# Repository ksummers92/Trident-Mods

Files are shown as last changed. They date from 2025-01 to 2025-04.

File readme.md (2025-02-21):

- Reaper Toolhead Mods directory contains mods/remixes used that relate to the [Reaper Toolhead](https://github.com/APDMachine/Reaper) ecosystem.
- Gantry Blobifier is a modified version of [Blobifier_X](https://github.com/xuanyuanss/Blobifier_X) which is a variant of [Blobifier](https://github.com/Dendrowen/Blobifier).

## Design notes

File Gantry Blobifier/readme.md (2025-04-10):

# Gantry-Attached Blobifier
## A variant of Blobifier for fixed XY gantry printers

First of all, this variant is based heavily on the "[Blobifier_X](https://github.com/xuanyuanss/Blobifier_X)". Credit to the originator for a great idea!

The Blobifier hardware is wholly incompatible with fixed gantry printers such as the Voron Trident.

There are variations of the "software" that the Blobifier uses to operate that allow one to purge blobs onto the bed and then kick them off. However, this method poses similar and additional issues that are present in the original Blobifier.

1. An area of the build plate is lost/reserved for purging in both the original Blobifier (primarily for toolhead clearance) and the Trident/SW variant of blobbing on the build plate.
1. The Trident/SW variant has a further limitation due to the need to raise the bed/lower the X-axis gantry to bed which either limits the height of parts to the height of the toolhead below the gantry or makes it not possible to use the Blobifier for parts taller than that dimension.

While attempting to implement the Blobifier_X, I found that the unipolar stepper motor (despite "conversion" to a bipolar stepper) was inadequate for the task and tempermental. Therefore, I decided to make some modifications to the original design to enable the use of a NEMA 17 stepper that I had laying around.

> Note: While I designed this for my Trident, the original designer designed theirs for the V2. Therefore, this could in theory be used for a V2 also. However, there are certain design considerations that would need taken into account for this version to work effectively with a V2. Primarily, overall height of the setup would need to be closely considered to allow the gantry to still reach the build plate. The weight is also a factor to consider. However, the advantage of not losing build area may be worth it.

# Images
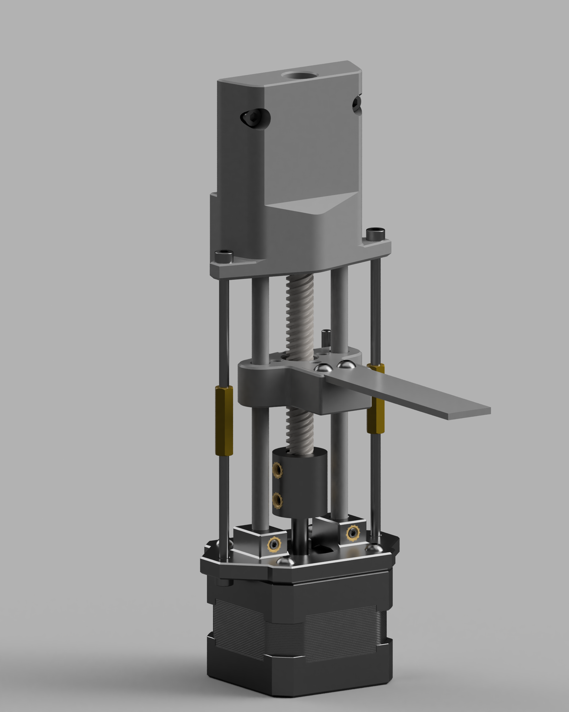
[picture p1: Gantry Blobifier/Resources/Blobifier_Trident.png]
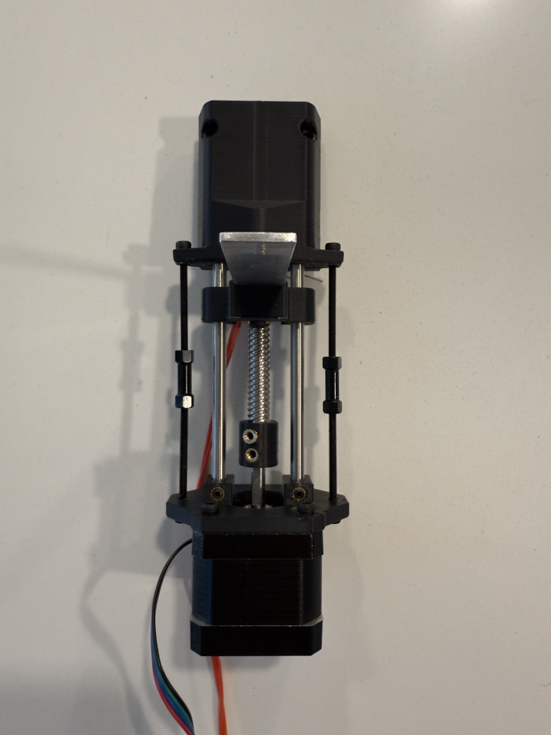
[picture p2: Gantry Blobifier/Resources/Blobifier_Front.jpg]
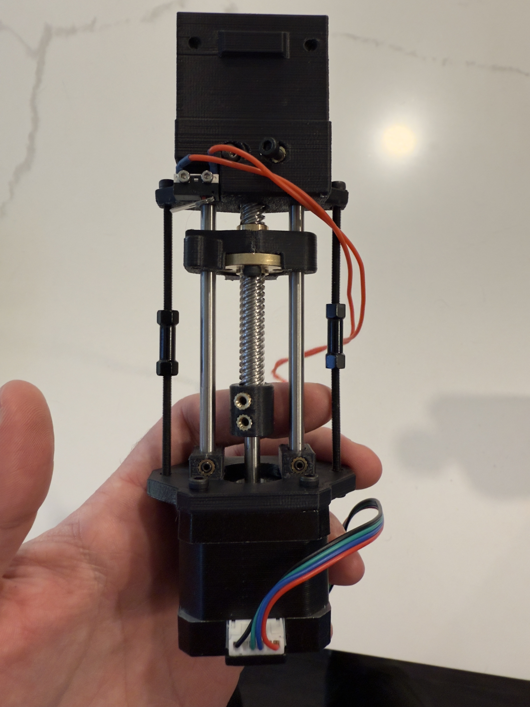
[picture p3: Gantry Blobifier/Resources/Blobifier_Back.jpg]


# In Action
Watch the Video (https://youtu.be/DP9UL1YaNPk)

> WARNING: Improper configuration of this setup and macro could result in damage to your printer. I am not responsible for any damages caused as a result of your actions. That being said, I am willing to assist if you are having any issues.

# Bill of Materials:
- 1x NEMA 17 stepper motor, I do not think that the size is important since the assembly is relatively light, so opt for the smallest variant you have on hand.
- 1x TMC2209 or any bipolar stepper motoro driver
- 2x ∅5x100mm steel dowel
	- I used 100mm length, but this can be tuned to your setup. 100mm works well with the Reaper Toolhead using a Rapido UHF hotend where the nozzle tip sits ~49mm below the bottom side of the gantry extrusion.
- 1x 100mm T8 lead screw with nut
	- Again, the length can be changed for your setup. There is some forgiveness in the length since the top side is not fixed in place
	- Generally, the length should be the same as the length of the dowels you chose.
- 1x D2F-L1 micro switch, knockoff Omrons work too
- Some amount of M3x4x5 heatset inserts (~12? ¯\\_(ツ)_/¯)
- 4-8x M3x3 set screws
	- Minimum 4 if you decide to print the coupler, optional additional 4 (8 total) if you want to use set screws for attach the stepper mount to the rods.
- 2x M3x12 SHCS for attaching to 2020 extrusions
- 2x t-nuts for 2020 extrusion attachment
- 4x M3x8 BHCS or SHCS for attaching stepper to stepper mount
- 2x M3x12 BHCS for securing rods to main body
	- Could use longer set screws too
- 1x M3x? BHCS or SHCS for endstop positioning
	- Length is variable because it depends on your setup
- 2x M3x6 BHCS or SHCS for mounting tray to slider
- 4x M3x40mm BHCS or SHCS for support rods
	- Length of these will depend on the length of the dowels that you choose and the length of spacer you have.
	- Generally, the length of the screws should be less than half the length of the rods (recommend (length_of_rod/2)-10) and choose spacer appropriately.
- 2x M3x25mm spacer for mating the support bolts together
	- <s>Strictly speaking, these and the 40mm bolts above may not be necessary, but I added them as a backup in the event that the screws holding the rods in place backed out over time from vibrations. You can add loctite to these, I would not recommend adding loctite to the screws holding the rods. </s>
	- After extended use, when I took the blobifier apart, I found that my set screws had loosened. Therefore, I believe that these support rods are good insurance.
- 1x 15x2x?mm aluminum bar for tray
	- You want this long enough to extend about 4-5mm past nozzle when nozzle parked over tray.
	- I suggest buying longer than needed and cutting to length once you have everything mocked up.
	- Drill holes into bar as shown below
- Masking tape, aids in adherence of blob to tray. Other methods could also work, this just worked for me.

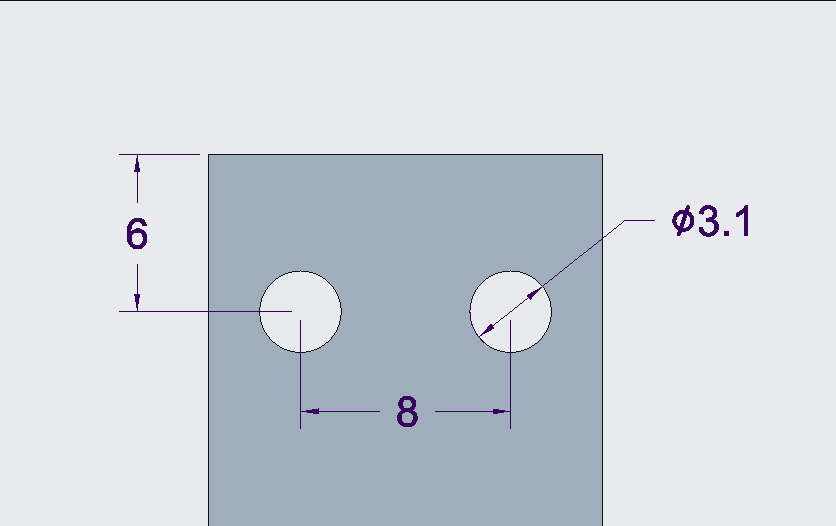
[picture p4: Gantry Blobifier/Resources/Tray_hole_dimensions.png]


# Key Assembly Instructions
- If using printed coupler, I suggest installing the stepper mount shaft and T8 rod into coupler and then pressing the heatset insert all the way until it stops against the shaft/rod.
- Assemble the main body and the stepper motor mount with the rods, then install the T8 shaft with the coupler onto the stepper motor before attaching stepper to the mount.
- If using the printed standoff, there are two options for attaching with bolts: insert a M3 nut into the recess or use a M3x5x4 heatset insert. 
	- There is no need to torque the support bolts significantly as they are just keeping the assembly together. Overtorquing may lead to printed part failure, so use the Voron adage "Tighten until the plastic bends and cracks. Back up 2 turns, discard parts, reprint and try again".

# Setup Instructions
## Basic Configuration
- Copy blobifier_trident.cfg and blobifier_trident_hw.cfg to config folder.
	- Add [include blobifier_trident.cfg] and [include blobifier_trident_hw.cfg] to printer.cfg
- Update the pin definitions, rotation distance, etc. in blobifier_trident_hw.cfg to match your setup.
- Check the stepper motor direction by manually putting the slider in the middle of the travel, then run `MANUAL_STEPPER STEPPER=blobifier MOVE=5`. If the slider moves away from the microswitch (down), then the direction is correct. Otherwise, invert the DIR pin in the blobifier_trident_hw.cfg.
> NOTE:
> MANUAL_STEPPER works differently than you might expect if you haven't used it before. Klipper keeps track of the position of a manual stepper (between restarts that is), so running the above `MANUAL_STEPPER STEPPER=blobifier MOVE=5` again will result in no movement until a firmware restart or one issues `MANUAL_STEPPER STEPPER=blobifier SET_POSITION=0` to reset the stored position. Keep this in mind when testing correct movement.
## Home Position Setting
- Install the bumpstop screw into slider if you have not already
- Manually adjust the slider position such that the tray sits approximately 0.2 - 0.6mm below the nozzle.
	- Recommended to move the toolhead manually into position.
- Adjust the bumpstop screw until you hear the microswitch click.
- Move the toolhead clear of the tray
- Run `BLOBIFIER_RESET`, then `MANUAL_STEPPER STEPPER=blobifier MOVE=5` to move the slider away from the microswitch. Then run `BLOBIFIER_HOME`. The slider should move up and then stop when the microswitch is activated.
- Move the toolhead back over the tray (careful to make sure that it does not collide with the tray) and check the distance between the nozzle and the tray. If the distance is still ~0.2 - 0.6mm, then no more adjustment is needed. 
	- If it is too close to the nozzle or the nozzle would collide with the tray, then run `BLOBIFIER_RESET` and `MANUAL_STEPPER STEPPER=blobifier MOVE=5` again, thread the bumpstop screw in further, run `BLOBIFIER_HOME` again, then check the distance again.Repeat as necessary.
	- If the tray is too far away, loosen the bumpstop screw enough that you think it will provide the necessary gap (M3 screws have a 0.5mm pitch, so one turn/rev = 0.5mm in linear distance). Run `BLOBIFIER_RESET` then `MANUAL_STEPPER STEPPER=blobifier MOVE=5` and then `BLOBIFIER_HOME` again. Check the distance. Repeat as necessary.
- Once you are confident that the nozzle is at a good distance and will not collide with the tray, then home the XY axes and move the nozzle over the tray, making sure to center it as best as possible. Record the X and Y coordinates (the Y coordinate is usually the same as the axis maximum). These coordinates correspond to the purge_x and purge_y variables in the blobifier_trident.cfg.
- Additionally, define the kick_ready_x, kick_x, and kick_y coordinates.
	- The kick_ready_x position should be to the left or right of the purge_x position and provide enough distance to build up to the blob_kick_spd you set in the config.
	- The kick_x position must at least be the same as purge_x in order to contact the blob on the tray. I set mine a bit past it (to left of purge_x if my kick_ready_x is to the right) to follow through on the kick to make sure I make contact.
	- If you are kicking with the nozzle silicone sock, then kick_y will be the same as the purge_y value. If you are kicking with something else (I use the part of my beacon where it mounts to the carriage, more rigid and generally cheaper/easier to replace than a hotend if something bad were to happen...), then you will input a kick_y position that works for you.
- Finally, go through the BLOBIFIER gcode variables and set the other variables as necessary. Many of them are the same as the OG [Blobifier](https://github.com/moggieuk/Happy-Hare/blob/main/config/addons/blobifier.cfg) variables found in the Happy Hare repo.

## Advanced Configuration
TBD

# Printing Suggestions
- Standard Voron printing profile should be sufficient.
- I printed these parts with ASA. They might work with PLA, but I cannot guarantee it.
- The print orientation of the stls is not guaranteed. However, the orientation should like the image below. The slider has a built in support that can be removed easily by slotting a flat head in the gap and twisting.
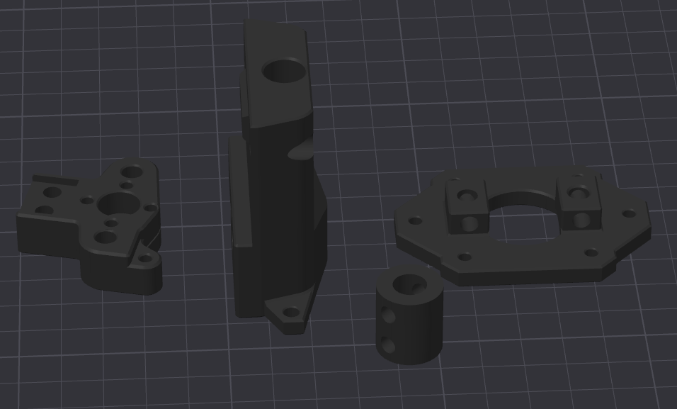
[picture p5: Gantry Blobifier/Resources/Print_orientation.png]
- 
	- Note that the coupler (if you choose to use it) should be printed with the 5mm end down on the build plate.
- If you choose to use the printed standoff, it was designed to be printed laying down to prevent separation at layer lines in operation. Orient it as shown below for best performance.
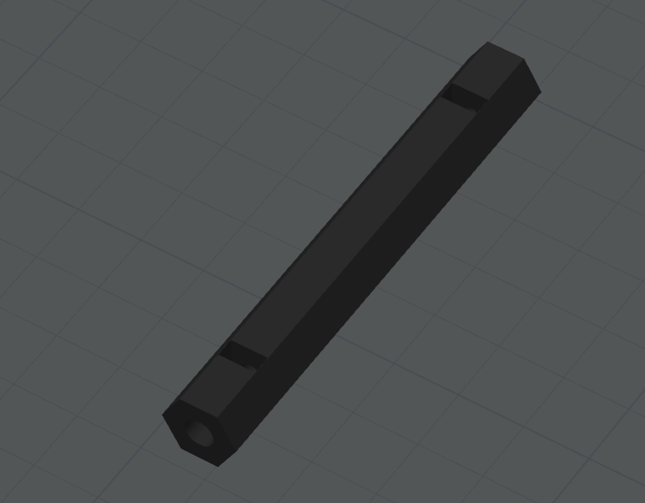
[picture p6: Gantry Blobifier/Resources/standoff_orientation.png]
	- 

# Other Considerations
- The originator of the [Blobifier_X](https://github.com/xuanyuanss/Blobifier_X) also includes a kick attachment for Stealthburner toolheads. However, if you are using Filametrix, then it will be incompatible as it mounts to one of the mounting points used by Filametrix.
- Thank you to the Blobifier_X creator for laying the groundwork for this project.
- Thank you to @Dendrowen for his original creation of the Blobifier.

- If you run into any issues, please raise an issue here or contact me on discord (ksummers92)

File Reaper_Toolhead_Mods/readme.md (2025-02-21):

## List of Mods
 - [WWG2 Dual Sensor Front Body coupling plate mount](WWG2_Dual_Sensor_Front_Body_coupling_plate_mount.stl) is a modification of the WWG2 front body by bythorsthunder found [here](https://github.com/bythorsthunder/Voron_Mods/tree/main/Wristwatch_G2_Dual_Filament_Sensor) with the addition of a mounting point for the "Extruder Coupling Plate" found in this folder.
 - [Extruder Coupling Plate](Extruder_Coupling_Plate.step) is a modification to create a third mounting point for the WWG2 extruder to the hotend mount of the Reaper toolhead that uses the Xol mount pattern.
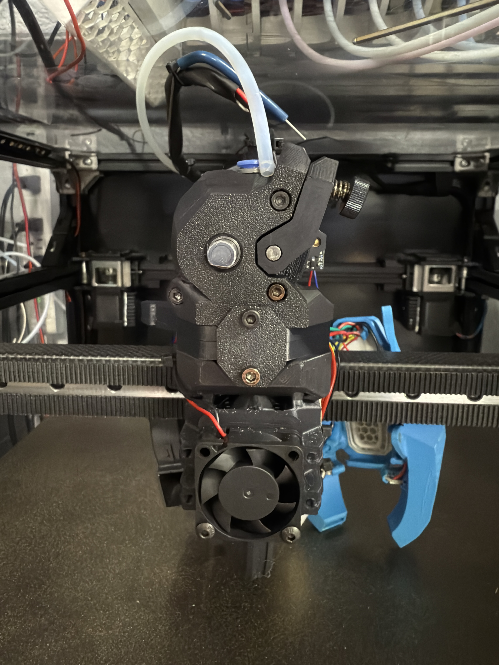
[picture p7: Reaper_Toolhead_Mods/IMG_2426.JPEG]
	- Here is a picture of the coupling plate: 
 - [Cutter](Cutter) folder contains parts for a cutter mod that were derived from this [cutter](https://www.printables.com/model/1142687-filament-cutter-for-reaper-toolhead-and-orbiter-pa) by @mental808.
	- All parts have been modified for better functionality as a XY cutter mechanism.
	- V2 parts use an updated cutter arm that is hopefully more robust.
		- Bottom V2 is slightly taller (0.3mm) to eliminate need to sand cutter arm during assembly as well.
	- The parts were modeled to better align with the profile of the WWG2 and Reaper hotend mount as well as shave off 4 mm in overall height.
	- At some point I will add some more tips and tricks that I learned with the cutter installation on Reaper when I get time.

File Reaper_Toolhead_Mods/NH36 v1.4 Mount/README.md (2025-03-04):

## LDO NiteHawk 36 V1.4 Board Mount for WWG2 with PG7
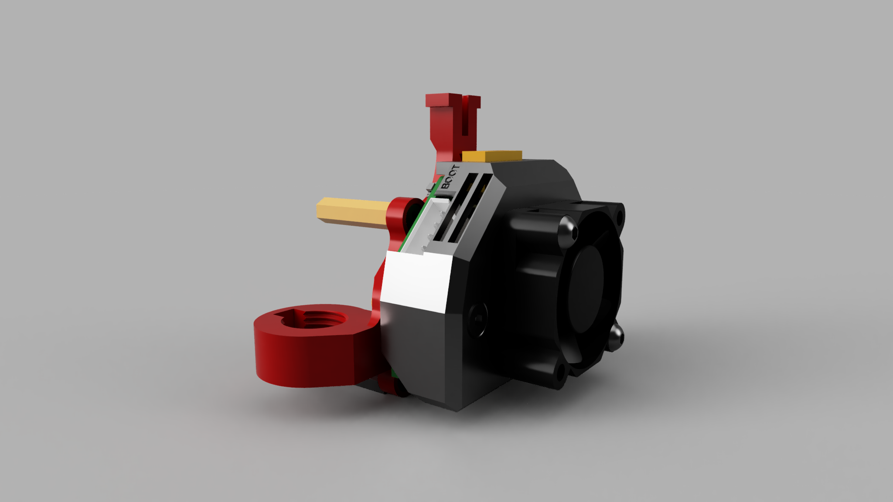
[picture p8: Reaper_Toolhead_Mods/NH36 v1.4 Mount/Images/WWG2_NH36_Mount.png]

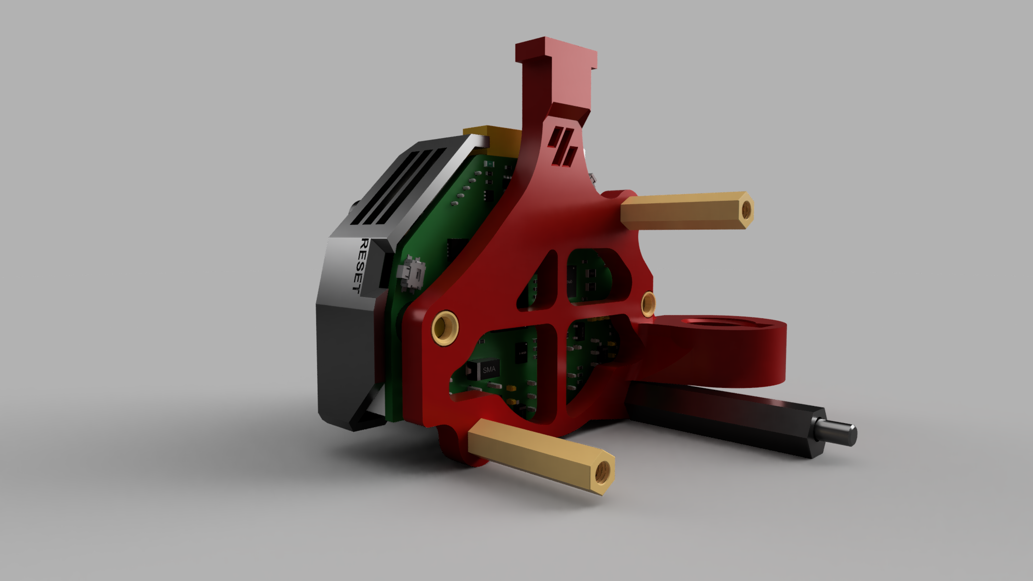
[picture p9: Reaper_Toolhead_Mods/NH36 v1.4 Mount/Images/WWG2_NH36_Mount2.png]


This mount is basically a remix of this [PG7 mount](https://github.com/tetsu97/WristWatch-G2-Extruder/blob/main/STLs/CANBoard_Mounts/CANBoard_Mount2(PG7)_nospacer.stl) with an added third mounting point for WWG2. There are added spacers to distance the board from the mount. I have also made some other slight modifications that make it more compatible with NiteHawk 36 V1.4.

The mount also features a PTFE tube strain relief/piano wire mount point that was inspired by @hartk1213's [NH36 mount](https://github.com/hartk1213/MISC/tree/main/Voron%20Mods/Extruders/nitehawk36_mount_and_cover). I mainly use it on my Trident as a place to mount the piano wire that I zip tie my umbilical to.

I have also created a cover specific to NH36 V1.4 with a fan mount incorporated (as we know that these boards do not like high temperatures...).

---

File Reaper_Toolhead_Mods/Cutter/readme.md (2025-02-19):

These files are still in testing more or less. CAD says that they will work, but the cutter arm parts have yet to be printed and tested.

That being said, please let me know if you find any issues!

## Cutter Arm Improvements
- Depressor arc implemented to hopefully enable smoother cutter action. I found that the original cutter arm design was very noisy.
	- This design was also chosen to work better with the two-dimensional cutter action that I coded into Happy Hare for these types of cutters.
		- This has not been released, but the details can be found [here](https://github.com/moggieuk/Happy-Hare/pull/607) if you wish to test it out!
- The pin behind the opening for the blade was also eliminated as the iterations that I have tested were consistently failing there.
	- The indexing points are not a ring around the pivot pin in the arm bottom part and another pin about where the original was.
- I was not able to figure out a way to not use super glue to attach the two halves together, so that is still the recommended method of construction.
## Cutter V2
- I had the cutter arm break on me again, so I modified the arm to hopefully distribute the forces from the cutting action.
- I primarily hope to achieve this by bracing the other side of the part surrounding the filament path. The arc shape is not ideal from a loading perspective, but it should take some of the stress off the other side of the cutter arm.
- Picture below illustrates the tensile forces (red) and the compressive forces that will be experienced by the two parts of the cutter arm.
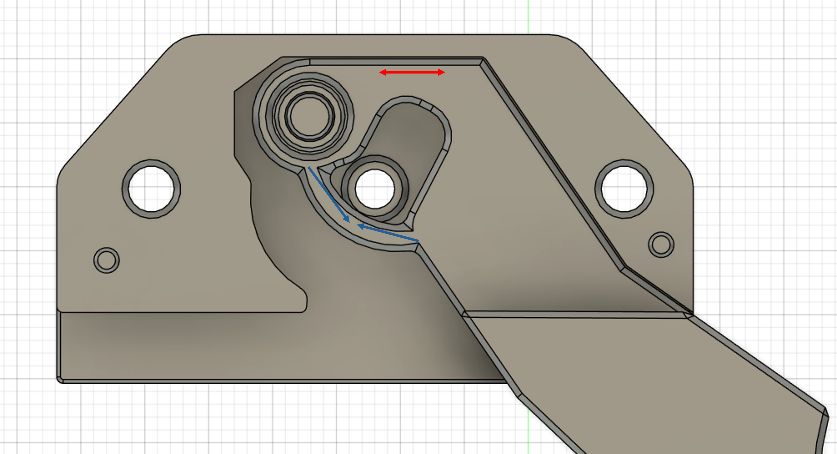
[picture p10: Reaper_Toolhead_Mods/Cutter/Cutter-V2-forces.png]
	- 

## Other notes about assembly
- Once you have the two halves and the cutter arm installed, I would press the two halves together (a vice would be handy here) and check the motion of the arm. If it is binding, then I would suggest sanding the top and bottom surfaces of the cutter arm that fall within the gap in the top and bottom housing. You want it to move freely so that it can spring back after the cut.
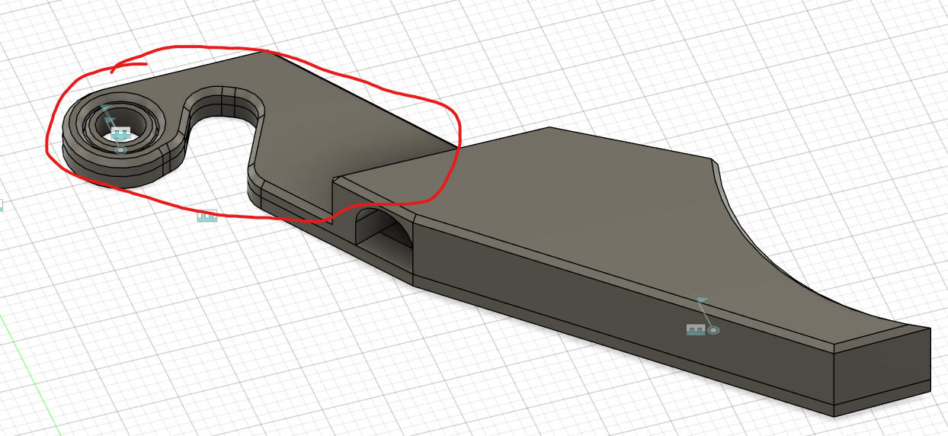
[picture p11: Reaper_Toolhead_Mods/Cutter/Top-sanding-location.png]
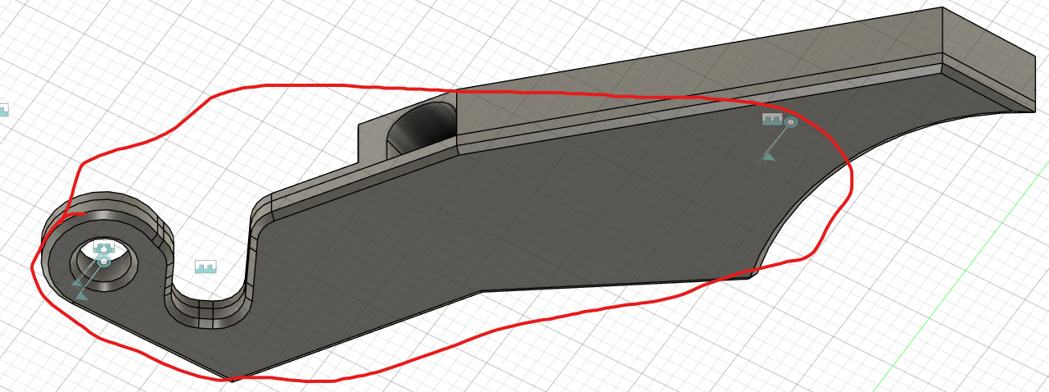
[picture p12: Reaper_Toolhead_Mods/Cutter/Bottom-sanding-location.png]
	-  

## Gantry-mounted servo
- The gantry-mounted servo file is a slight remix of this [one](https://www.thingiverse.com/thing:6584232) with a bolt hole spacing of 41.5mm to work with my gantry backers
- The servo arm depressor is a mix of the arm from [here](https://www.thingiverse.com/thing:6584232) and the pushbar from [here](https://www.printables.com/model/1142687-filament-cutter-for-reaper-toolhead-and-orbiter-pa/files) so that I could save some bed space.

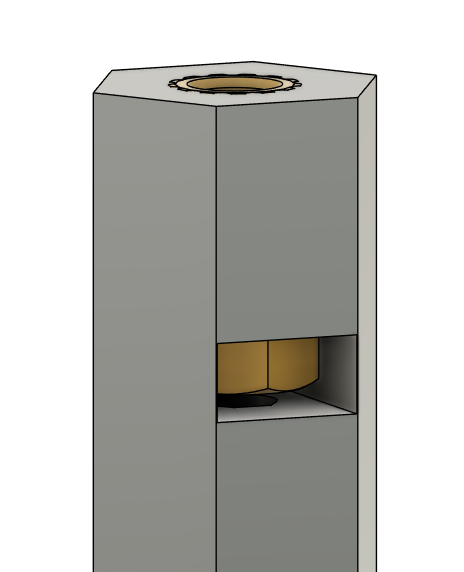
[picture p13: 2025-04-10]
Gantry Blobifier/Resources/Standoff_example.png

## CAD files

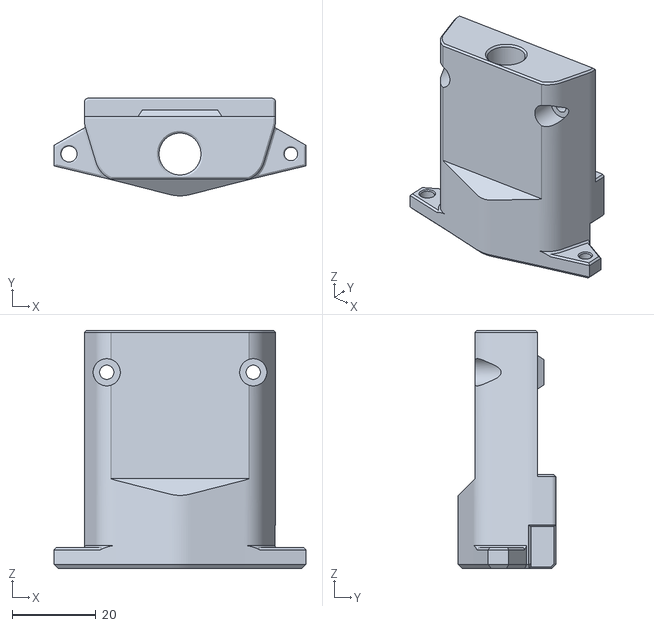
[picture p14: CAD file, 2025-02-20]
Gantry Blobifier/STLs/Main_Body.stl
60.2 x 23.3 x 56.9

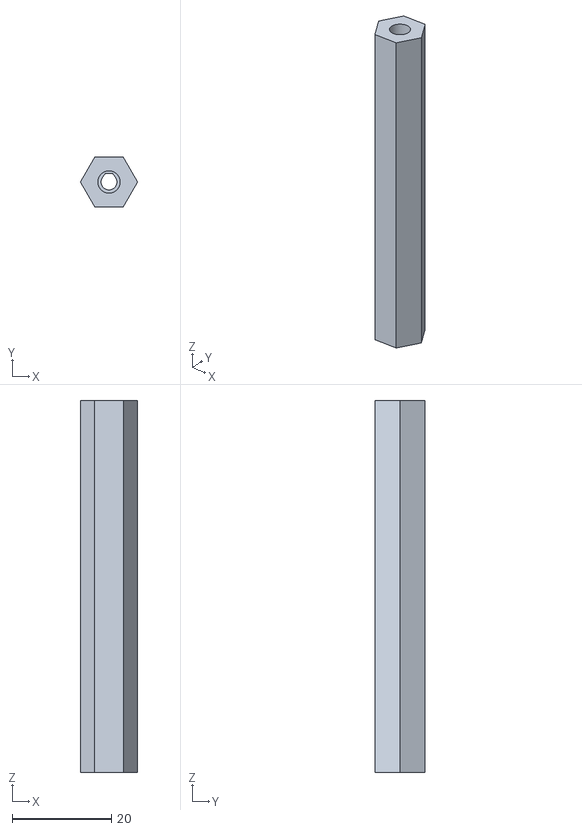
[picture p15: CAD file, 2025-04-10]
Gantry Blobifier/STLs/Blobifier_standoff_voron_heatset.stl
11.5 x 10.0 x 75.0

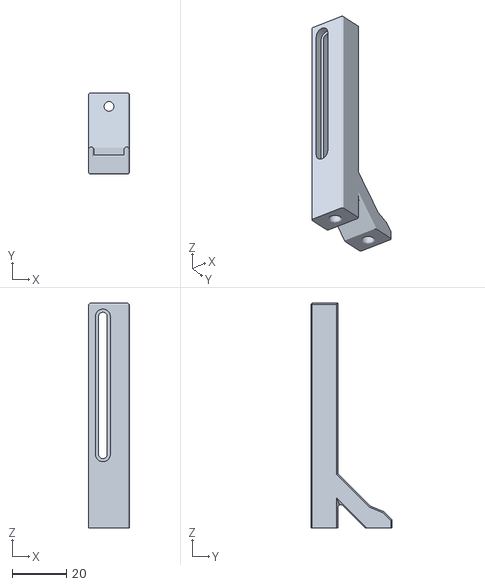
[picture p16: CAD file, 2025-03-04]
Gantry Brush/Brush Mount.stl
15.0 x 30.0 x 83.0

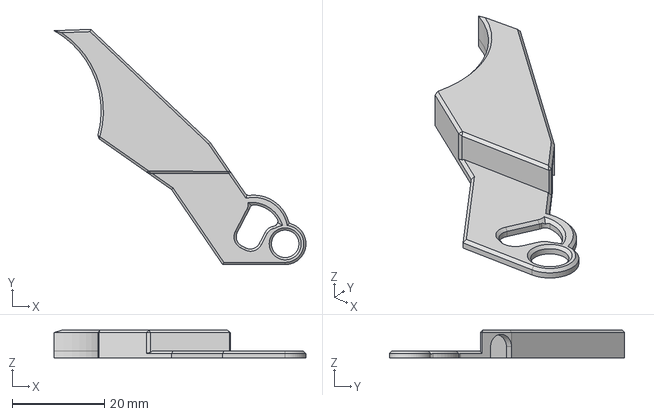
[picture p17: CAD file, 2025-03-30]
Reaper_Toolhead_Mods/Cutter/Cutter Arm Top V2.step
54.6 x 51.0 x 5.97 mm

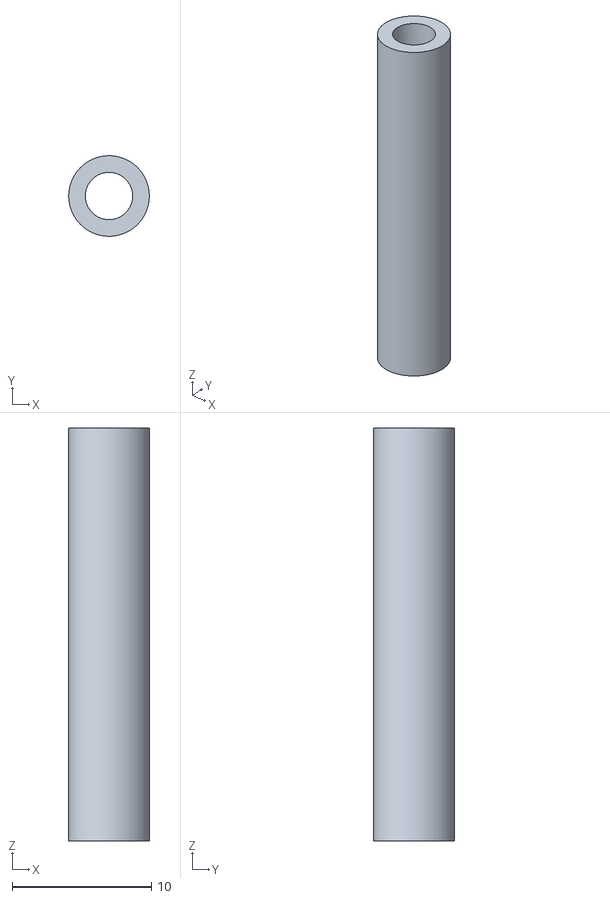
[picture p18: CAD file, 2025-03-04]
Reaper_Toolhead_Mods/NH36 v1.4 Mount/STL/NH36 v1.4 PG7 Mount Spacer v1.stl
5.80 x 5.80 x 29.7

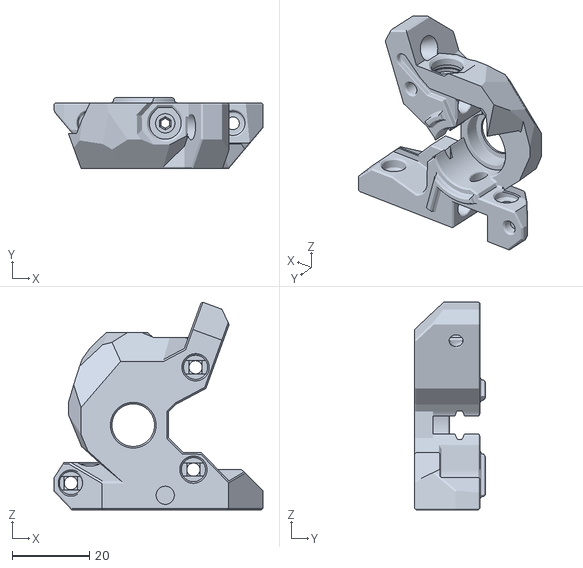
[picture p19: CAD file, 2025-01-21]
Reaper_Toolhead_Mods/WWG2_Dual_Sensor_Front_Body_coupling_plate_mount.stl
54.1 x 18.4 x 53.7

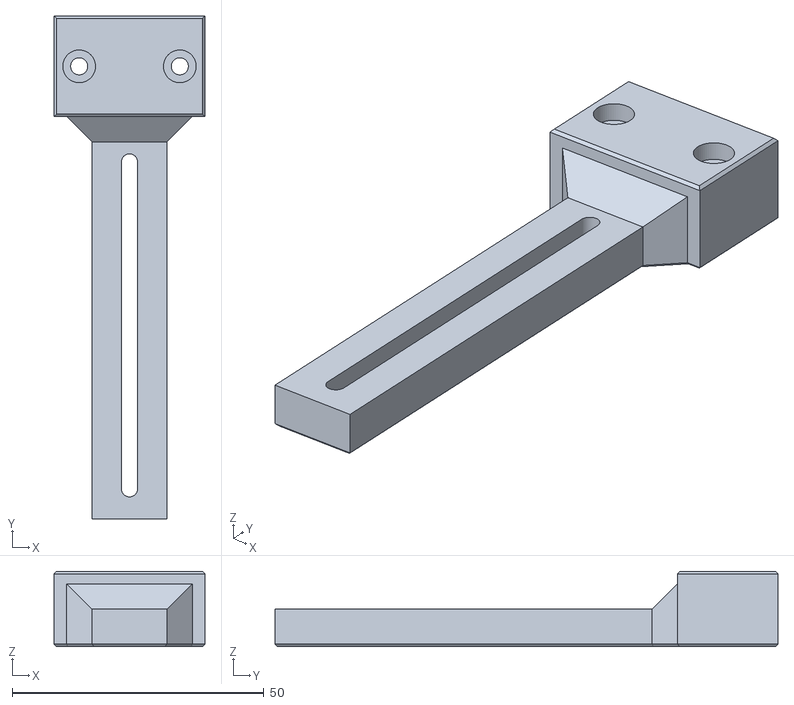
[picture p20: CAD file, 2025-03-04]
Gantry Brush/Gantry Mount.stl
30.0 x 100.0 x 15.0

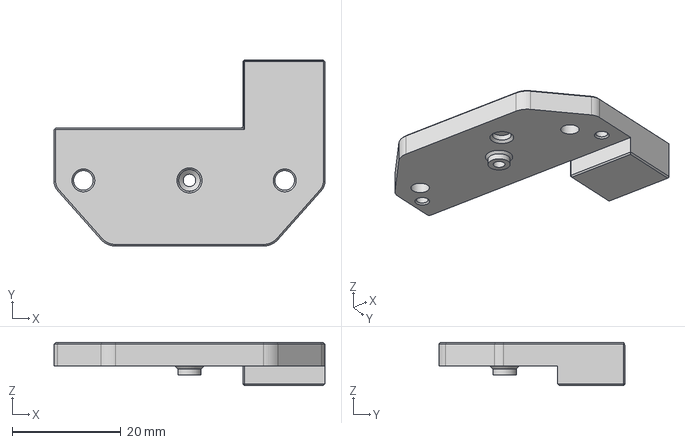
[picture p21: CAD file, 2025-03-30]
Reaper_Toolhead_Mods/Cutter/Reaper_Cutter-Top.step
49.8 x 34.2 x 7.92 mm

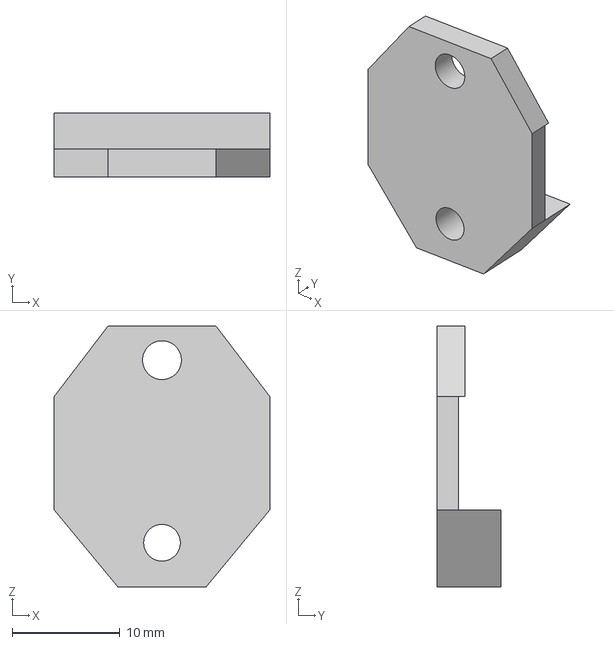
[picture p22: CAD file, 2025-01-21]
Reaper_Toolhead_Mods/Extruder_Coupling_Plate.step
20.0 x 5.92 x 24.2 mm

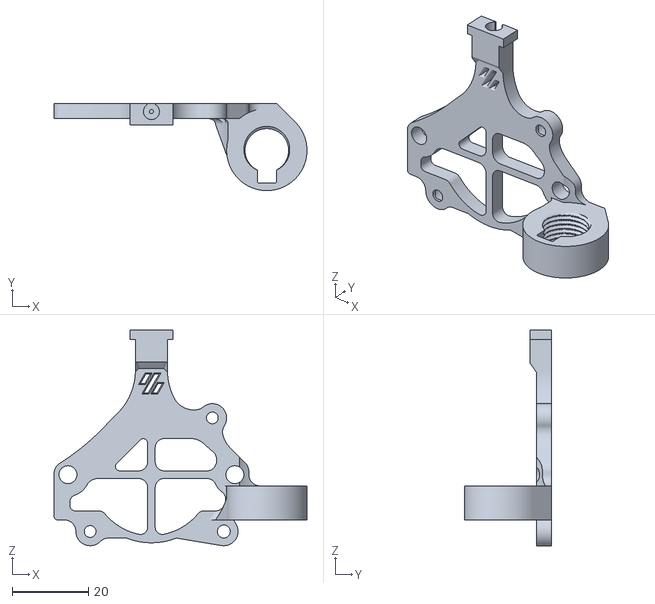
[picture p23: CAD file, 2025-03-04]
Reaper_Toolhead_Mods/NH36 v1.4 Mount/STL/WWG2_NH36_PG7_Mount.stl
66.4 x 22.9 x 56.6

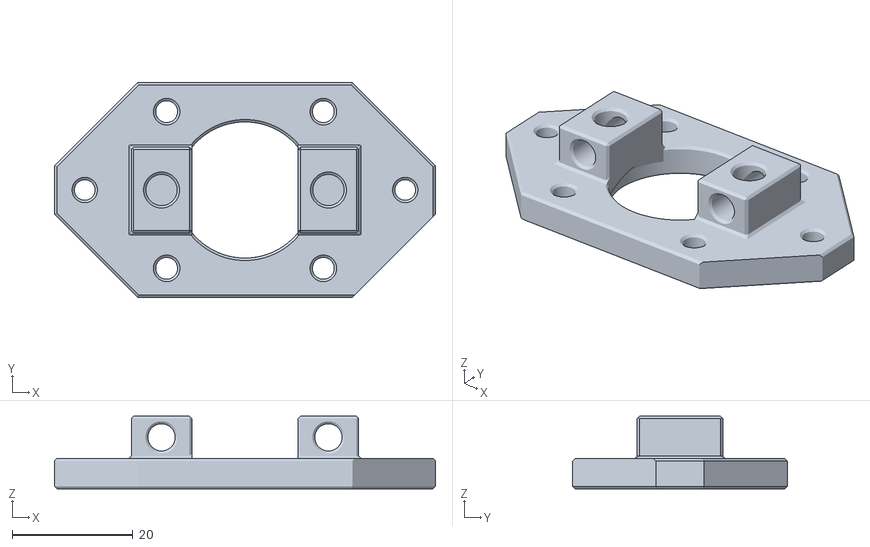
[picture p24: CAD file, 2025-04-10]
Gantry Blobifier/STLs/Stepper mount - NEMA 14 v1.stl
63.0 x 35.5 x 12.0

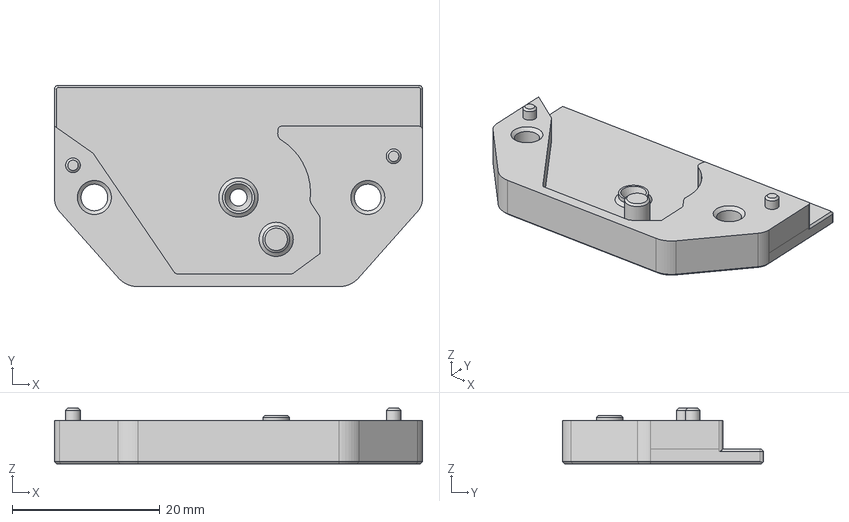
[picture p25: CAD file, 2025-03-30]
Reaper_Toolhead_Mods/Cutter/Reaper_Cutter-Bottom V2.step
49.8 x 27.3 x 7.56 mm

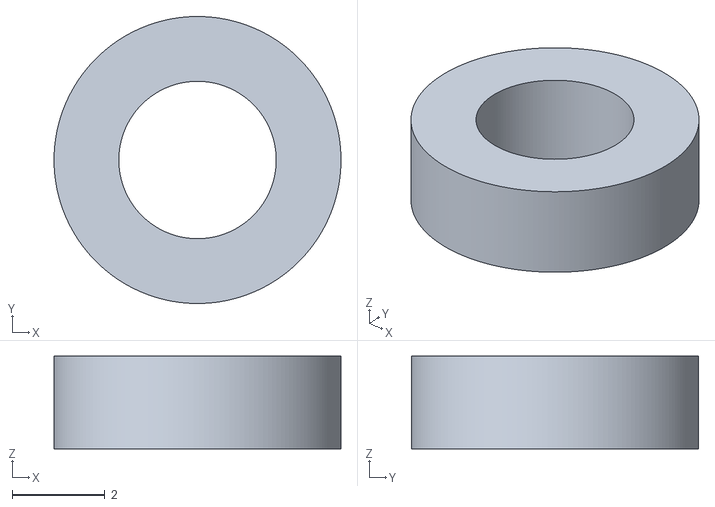
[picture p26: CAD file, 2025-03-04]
Reaper_Toolhead_Mods/NH36 v1.4 Mount/STL/NH36 v1.4 board mount Spacer v3.stl
6.20 x 6.20 x 2.00

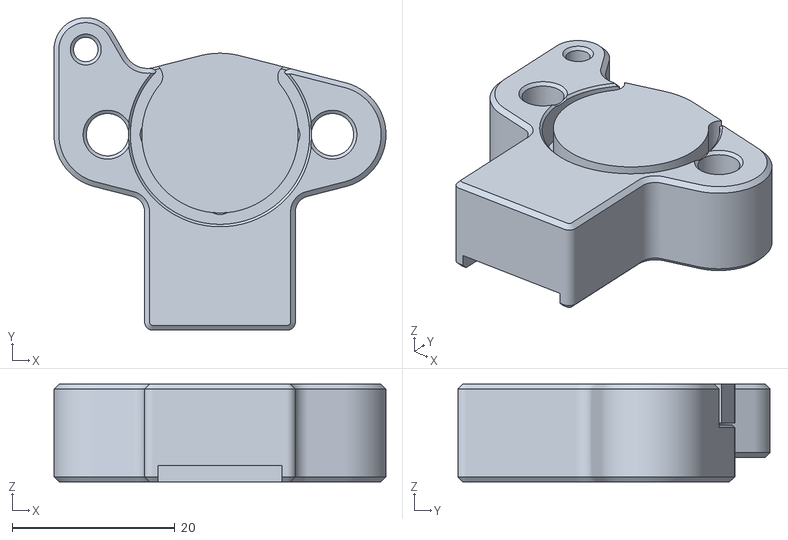
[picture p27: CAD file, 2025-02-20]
Gantry Blobifier/STLs/Slider.stl
40.7 x 38.3 x 12.0

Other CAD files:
Gantry Blobifier/STLs/Blobifier_standoff_M3x5.7.stl
Reaper_Toolhead_Mods/Cutter/Cutter Arm Bottom V2.step
Reaper_Toolhead_Mods/NH36 v1.4 Mount/STL/NH36 v1.4 PG7 Mount Spacer v2.stl
Reaper_Toolhead_Mods/Cutter/Cutter Housing Top V1&2.stl
Gantry Blobifier/STLs/Blobifier Coupler.stl
Gantry Blobifier/STLs/Stepper Mount - NEMA 17.stl
Reaper_Toolhead_Mods/Cutter/Bottom V2.stl
Reaper_Toolhead_Mods/Cutter/Cutter Arm Bottom V2.stl
Reaper_Toolhead_Mods/Cutter/Cutter Arm Bottom.step
Reaper_Toolhead_Mods/Cutter/Cutter Arm Bottom.stl
Reaper_Toolhead_Mods/Cutter/Cutter Arm Top v2.stl
Reaper_Toolhead_Mods/Cutter/Cutter Arm Top.step
Reaper_Toolhead_Mods/Cutter/Cutter Arm Top.stl
Reaper_Toolhead_Mods/Cutter/Gantry-mounted servo.stl
Reaper_Toolhead_Mods/Cutter/Reaper_Cutter-Bottom.f3d
Reaper_Toolhead_Mods/Cutter/Reaper_Cutter-Bottom.step
Reaper_Toolhead_Mods/Cutter/Reaper_Cutter-Top.f3d
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

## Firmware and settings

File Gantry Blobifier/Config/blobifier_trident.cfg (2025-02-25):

##########################################################################################

# Sample config to be used in conjunction with Gantry Blobifier mod 
# Created by Kodi Summers (ksummers92 on Discord). The Macro is based on the Blobifier macro
# with some variations to accommodate the difference with the hardware used in this variant.

# The goals of this combination of devices is to dispose of purged filament during a 
# multicolored print without the need of a purge block and without the flurries of
# filament poops consuming your entire 3D printer room. The Blobifier achieves that by
# purging onto a retractable tray which causes the filament to turn into a tiny blob 
# rather then a large spiral. This keeps the waste relatively small. 

# It is advised to use the start_gcode from Happy Hare. Then you will be able to fully 
# and efficiently use this mod. Check the Happy Hare document at gcode_preprocessing.md 
# in the Happy Hare github for more details.

###################################### DISCLAIMER ########################################

# You, and you alone, are responsible for the correct execution of these macros and 
# gcodes. Any damage that may occur to your machine remains your responsibility. 
# Especially when executing this macro for the first few times, keep an eye on your 
# printer and the 
# emergency stop.

##########################################################################################

##########################################################################################
# Main macro. Usually you should only need to call this one or place it in the Happy Hare
# _MMU_POST_LOAD macro using the variable_user_post_load_extension:
#
# variable_user_post_load_extension : `BLOBIFIER`
#
# Notes on parameters:
# PURGE_LENGTH=[float] (optional) The length to purge. If omitted (default) it will check
#                      the purge_volumes matrix or variable_purge_length. This can be used
#                      to override and for testing.
#
[gcode_macro BLOBIFIER]
# These parameters define your filament purging.
# Note that the control of retraction is set in 'mmu_macro_vars.cfg' which can be increased
# if you experience excessive oozing.
variable_purge_spd: 400                 # Speed, in mm/min, of the purge.
variable_purge_temp_min: 200            # Minimum nozzle purge temperature.
variable_toolhead_x: 55                 # From the nozzle to the left of your toolhead
variable_toolhead_y: 45                 # From the nozzle to the front of your toolhead



# These parameters define your scrubbing, travel speeds, safe z clearance and how many
# times you want to wipe. Update as necessary.
variable_clearance_z:           2          # When traveling, but not cleaning, the
                                           #   clearance along the z-axis between nozzle
                                           #   and brush.
variable_travel_spd_xy:     10000          # Travel (not cleaning) speed along x and
                                           #   y-axis in mm/min.
variable_blob_kick_spd:     5000         # Speed to kick blob off 
variable_travel_spd_z:       100          # Travel (not cleaning) speed along z axis
                                           #   in mm/min.

variable_wipe_qty:              2          # Number of complete (A complete wipe: left,
                                           #   right, left OR right, left, right) wipes.
variable_wipe_spd_xy: 10000          # Nozzle wipe speed in mm/min.

# The acceleration to use when using the brush action. If set to 0, it uses the already 
# set acceleration. However, in some cases this is not desirable for the last motion 
# could be an 'outer contour' acceleration which is usually lower.
variable_brush_accel: 0

# These parameters define the size of the brush. Update as necessary. A visual reference
# is provided below.
#
#                  ←   brush_width   →
#                   _________________
#                  |                 |  ↑                Y position is acquired from your
#  brush_start (x) |                 | brush_depth       stepper_y position_max. Adjust
#                  |_________________|  ↓                your brush physically in Y so
#                          (y)                           that the nozzle scrubs within the
#                      brush_front                       brush.
# __________________________________________________________
#                     PRINTER FRONT
#
#
# Start location of the brush. Defaults for 250, 300 and 350mm are provided below.
# Uncomment as necessary
#variable_brush_start:          34  # For 250mm build
variable_brush_start:           90  # For 300mm build
#variable_brush_start:          84  # for 350mm build

# width of the brush
variable_brush_width: 20

# Blobifier sends the toolhead to the maximum y position during purge operations and
# minimum x position during shake operations. This can cause issues when skew correction 
# is set up. If you have skew correction enabled and get 'move out of range' errors 
# regarding blobifier while skew is enabled, try increasing this value. Keep the 
# adjustments small though! (0.1mm - 0.5mm) and increase it until it works.
variable_skew_correction: 0.1

# Location of where to purge. The tray is 15mm in length, so if you assemble it against 
# the side of the bed (default), 10mm is a good location
variable_purge_x: 271.5
variable_purge_y: 350
variable_kick_x:  261
variable_kick_y: 315
variable_kick_ready_x: 311
variable_yield_y: 295

# ========================================================================================
# ==================== BLOB TUNING =======================================================
# ========================================================================================

# The following section defines how the purging sequence is executed. This is where you 
# tune the purging to create pretty blobs. Refer to the visual reference for a better 
# understanding. The visual is populated with example values. Below are some guides 
# provided to help with tuning.
#
#                          \_____________/
#                             |___|___|
#                                \_/            ______________  < End of third iteration.
#                                / \                                  HEIGHT:   3 x iteration_z_raise - (2 + 1) x iteration_z_change  (3 x 5 - 2 x 1.2 = 11.4)
#                               |   |                                 EXTRUDED: 3 x max_iteration_length                              (3 x 50 = 150)
#                              /     \          ______________  < End of second iteration.
#                             |       \                               HEIGHT:   2 x iteration_z_raise - 1 x iteration_z_change        (2 x 5 - 1 x 1.2 = 8.8)
#                            /         |                              EXTRUDED: 2 x max_iteration_length                              (2 x 50 = 100)
#                           |           \       ______________  < End of first iteration. 
#                          /             \                            HEIGHT:   1 x iteration_z_raise                                 (1 x 5 = 5)
#                         |               |                           EXTRUDED: 1 x max_iteration_length                              (1 x 50 = 50)
#___________               \             /      ______________  < Start height of the nozzle. default value: 1.5mm
#           |_______________\___________/_      ______________  < Bottom of the tray
#           |_____________________________|
#           |
# 
########################### BLOB TUNING ##############################
# +-------------------------------------+----------------------------+
# |  Filament sticks to the nozzle at   | Incr. purge start          |
# |    initial purge (first few mm)     |                            |
# +-------------------------------------+----------------------------+
# |  Filament scoots out from under     | Incr. temperature          |
# |  the nozzle at the first iteration  | Decr. z_raise              |
# |                                     | Incr. purge_length_maximum |
# +-------------------------------------+----------------------------+
# |  Filament scoots out from under the | Decr. purge_spd            |
# |  the nozzle at later iterations     | Decr. z_raise_exp          |
# |                                     | Decr. z_raise              |
# |                                     | Incr. purge_length_maximum |
# +-------------------------------------+----------------------------+
# |  Filament sticks to the nozzle at   | Incr. z_raise_exp          |
# |         later iterations            |     (Not above 1)          |
# +-------------------------------------+----------------------------+
#
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

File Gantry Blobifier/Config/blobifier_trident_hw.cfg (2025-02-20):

[manual_stepper blobifier]
step_pin:   MCU_M6_STEP
dir_pin:    MCU_M6_DIR
enable_pin: !MCU_M6_EN
microsteps: 32
rotation_distance: 8
full_steps_per_rotation: 200
homing_speed: 5
velocity: 15
accel: 60
endstop_pin: BLOBIFIER_STOP

[tmc2209 manual_stepper blobifier]
uart_pin: MCU_M6_CS
#interpolate: True
run_current: 0.8
hold_current: 0.1
sense_resistor: 0.110
stealthchop_threshold: 0

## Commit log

2025-01-21 Initial commit of reaper mods
    [Extruder Coupling Plate.step, Reaper Cutter - Bottom.f3d, Reaper Cutter - Bottom.step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]
2025-01-21 Adding some documentation
    [WWG2 Dual Sensor Front Body coupling plate mount.stl]
2025-01-21 maybe this will work
    [Extruder_Coupling_Plate.step, Reaper_Cutter-Bottom.f3d, Reaper_Cutter-Bottom.step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]
2025-01-22 Fixed pivot pin location
    [Reaper_Cutter-Bottom.f3d, Reaper_Cutter-Bottom.step, Reaper_Cutter-Top.f3d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]
2025-01-22 Adding cutter arm
    [Cutter Arm Bottom.stl, Cutter Arm Top.stl]
2025-01-22 adding gantry servo depressor
    [Gantry-mounted servo.stl, Servo arm depressor.stl]
2025-02-04 cutter arm step files
    [Cutter Arm Bottom.step, Cutter Arm Top.step, Servo arm depressor.step]
2025-02-19 V2 of cutter arm and bottom
    [Bottom V2.stl, Cutter Arm Bottom V2.stl, Cutter Arm Top v2.stl]
2025-02-20 Adding Gantry Blobifier
    [Blobifier Coupler.stl, Main_Body.stl, Slider.stl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]
2025-02-20 Add config files
    [blobifier_trident.cfg, blobifier_trident_hw.cfg]
2025-02-25 Adding fan control and missing BLOBIFIER_RESET command
    [blobifier_trident.cfg]
2025-03-04 Adding Gantry Brush, Cutter update, NH36 V1.4 Mount
    [Bottom V2.stl, Brush Mount.stl, Gantry Mount.stl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]
2025-03-30 Cutter housing top stl
    [Cutter Housing Top V1&2.stl]
2025-03-30 Updated step files
    [Cutter Arm Bottom V2.step, Cutter Arm Top V2.step, Reaper_Cutter-Bottom V2.step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]
2025-04-10 Add NEMA 14 mount to blobifier and updated CAD
    [Stepper Mount - NEMA 17.stl, Stepper mount - NEMA 14 v1.stl]
2025-04-10 Add printed standoff and updates to readme
    [Blobifier_standoff_M3x5.7.stl, Blobifier_standoff_voron_heatset.stl]
